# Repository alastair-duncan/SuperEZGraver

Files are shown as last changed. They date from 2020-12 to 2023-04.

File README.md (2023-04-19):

# SuperEZGraver

This is the Super EZ Graver project documentation. If any of the documentation doesn't make sense or links are broken etc please let me know and I'll do my best to fix it.

## Background

I started engraving early in 2019 after coming across some engraving videos by [Shaun Hughes](https://www.youtube.com/c/express375/videos) on YouTube. I started off with some push engraving while I ordered up the parts for Shaun's "Home made hand engraving machine". I built one of these and proceeded to hack my way through some brass and copper practice plates and I also enjoy making jewellery with enamel. I have now aquired a microscope which has had a marked effect on my engraving, previously I used an optivisor with an added loupe but it is not adequate for my old eyes.

Shaun had the idea of a solenoid powered engraving system over 2 years ago and posted a video on [YouTube](https://www.youtube.com/watch?v=2177lFeMcNw) and one of the engraving forums. He wasn't the first to come up with the idea, as far as I can find out that was [Steve Lindsay back in 1979](https://www.handengravetools.com/air-engraver-evolution.htm). So its nothing new although the availability of cheap electronic components and the advent of 3d printing has enabled me to put these together to make the Super EZ Graver. He also has tinkered with a Rolson engraver uses an AC driven laminated solenoid and power is regulated using a fan speed controller [YouTube](https://youtu.be//Ke8bDoJ-2io). Jerry Moralles uses a similar tool to engrave coins very effectively: [YouTube](https://www.youtube.com/channel/UC4XOksM98SMPymVrHOIaOxg). He also has made some additions that allow for the mounting of small abrasive stones to mechanise sanding and finishing very effectively.

Prior to this the McShirley power mallet utilises very similar technology by using a solenoid with presets for power and speed and a number of potentiometers which are used for fine control, you can view their 1975 [patent here](https://patentimages.storage.googleapis.com/81/7c/a0/0b0333b2f1563e/US3921044.pdf). There is also a video showing the [McShirley Power Mallet in action](https://www.youtube.com/watch?v=bn_Ea9L7uJU)

The Super EZ Graver that I have built is based around a XRN-13/30TLS solenoid. This is a small tubular solenoid that is 13mm in diameter and 30mm long. It will not plow its way through all materials put before it. You may find that for your purpose it does not pack the punch that you want but it suits me. I've had to adapt my engraving so that it is a bit more refined, which I think is an improvement for me, I no longer bury the tool and break tips. There may be a solenoid out there that will give all of the power and finess that everyone needs in a small package but I doubt it, I suspect that more than one toolpiece will be required and hopefully I'll add more designs and information to this project when it becomes available.

The controller and power source can handle much more powerful solenoids but I've only tried out a couple, I've made a [list of the ones I've tried](docs/solenoids.md) and added some comments. If you've tried others let me know and I'll add them to the list.

There are now 2 versions of the controler that I've built. The original based on the Ardiono Uno and the newer version based on the Pi Pico. The Pi Pico does not require a separate PWM "speed" controller for regulation of the power sent to the solenoid.

[Ardiono Uno controller](Arduino.md)

[Pico controller](Pico.md)

# Handpiece

I've created two 3d modelled handpieces in the open source 3d modelling application [Blender](https://www.blender.org/). 

there are now mk2 and mk3 versions 

### Mk2 Handpiece

The [blender source files](docs/design/XRN13-30TLS/mk2/blender) are available to download as well as the [stl](docs/design/XRN13-30TLS/mk2/blender/stl). There is a YouTube video on how to [setup the handpiece](https://www.youtube.com/watch?v=aNY35ATTJbg) and also the [Mk2](https://youtu.be/sa4kAdcZSkc) version which has a brass sleve insert. This was first produced using petg but it may be better to use a more heat conductive material such as [ice9](https://tcpoly.com/shop/) for better heat dissapation. I've not tried this yet.

[Anarasha](https://www.youtube.com/channel/UCKSbczGXmN4zeG3NeuPGLAg) had a problem with the blender version of the 3D model as the blender model has tolerances built in to it which causes problems with his slicer(I think). He has kindly produced a [fusion360](docs/design/XRN13-30TLS/fusion360) model of the handpiece which has the [stl](docs/design/XRN13-30TLS/fusion360/stl) and STEP files if this suits you better.

There are also some variations contributed by [ps-bond](https://github.com/ps-bond) one of these will allow the use if the solenoid without removing the screw boss.

### Mk3 Handpiece

This handpiece has the addition of a mount for a 25mm fan and is experimental. It suits my hand size and is comfortable. There are no threads on this handle, it does require some 2.5mm machine screws and nuts and a threaded insert in the handle for a stroke length adjuster. STL can be found [here](docs/design/XRN13-30TLS/mk3/stl). There is a video of the handpiece available [here](https://youtu.be/Q9xFH1qhLhE). The handpiece works without the fan but if you want some additional cooling when pushing the Super EZ Graver hard then the fan really helps. Something like [this](https://www.google.com/search?q=micro+fan+25mm+12v+dc) I've used a 12v dc version but there are other voltages available.

### Mk1 Handpiece
The first handpiece that I made was fabricated from brass and delrin. A YouTube video is available for the [handpiece](https://www.youtube.com/watch?v=D4yPBS8mucQ) along with a video on the handpiece [design refinement](https://www.youtube.com/watch?v=ALAtECnq1Rg)

# Gravers et al

[Carbide rods - UK](http://intertool.co.uk.websitebuilder.prositehosting.co.uk/carbide-rod)

[Carbide rods - US](https://centennialcarbide.com/products-page/carbide-rod-blanks/)

[3/32" HSS graver blanks - UK](https://www.ebay.co.uk/itm/360515374956) or [Gloster Tooling Supplies](https://www.glostertooling.co.uk/)

[Carbalt gravers](https://www.airgraver.com/graver-blanks.htm)

[Graver sharpening templates](http://airgraver.com/sharpening.html)

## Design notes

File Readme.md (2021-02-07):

The original design by Alastair Duncan was absolutely amazing. 
However, upon printing it on my rather well tweaked printer, some of the parts were way too loose.
I thought I couldn't be the only one who had such issues, so I recreated the entire model in Fusion 360 for easy editing, scaled so all the parts fit when I printed them and decided to upload both my Fusion 360 and STEP file here so others could make easy changes without Blender as well. 

I also uploaded my versions of the STL files. 

The functionality hasn't been changed at all, just the tolerance of the threads.

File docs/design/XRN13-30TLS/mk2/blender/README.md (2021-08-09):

Remember to watch the [construction video](https://youtu.be/sa4kAdcZSkc)
This design requires 9/32" brass tubing (K&S has a suitable wall thickness) & a soldered brass peg

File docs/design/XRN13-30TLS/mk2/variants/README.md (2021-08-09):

handpiece_6.5mm_v2_1.stl - this is a variant on the V2 handpiece that does not require a brass tube fitted.
Barrel of the handpiece has been extended 4mm to accomodate the threaded section of the solenoid (so it is no longer essential to cut off the threaded section); internal space has been expanded slightly to allow for easier insertion.

Protruding length of the piston should be reduced to a minimum of 3.2mm - this will allow for 2.5mm extension of the collet.

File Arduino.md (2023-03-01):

# Arduino Uno Controller

## Parts list.

Some of the links are to google searches, this is because actual products will become unavailable at some point so a list of products that you can select from is probably better.

[Arduino Uno](https://store.arduino.cc/arduino-uno-rev3), this is a link to the official Uno page. You can get unofficial versions much cheaper. Other Arduinos can be used but this is a cost effective board which can be run off the same 12VDC power supply so makes it very convenient. [Ebay arduinos](https://www.google.com/search?q=arduino+uno+ebay&oq=Arduino+uno+ebay)

[Mosfet](https://www.google.com/search?q=15A+400W+DC+5V-36V+Mosfet) Link to google search for appropriate mosfet. This is used by the Arduino to send a pulse of electricity to the solenoid.

[PWM power controller](https://www.google.com/search?q=DC+6-60V+12V+24V+36V+48V+30A+PWM+DC+Motor+Speed+Controller+(PWM)) Link to google search for appropriate PWM opwer controller. This is used to control how much power is sent via the mosfet to the solenoid.

[Power Supply](https://www.google.com/search?q=DC+12V+5A+to+50A+Amp+110V+220V+Power+Supply+12V+-+AC+110+-+220) Link to google search for appropriate 12VDC power supply. The XRN-13/30TL solenoid draws a maximum of 23SuperEZGraverw which is around 1.8 amps so a 5amp power supply will be ample.

[Foot pedal - potentiometer](https://www.google.com/search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) Link to google search for potentiometer foot pedal. I use this for control of the PWM power controler. It is not absulutly necessary as you can use the potentiometer that comes with the PWM  controller. It does add some flexibility to allow alteration of how much power is transmmitted while engraving. If you want to use one of these you will need to remove the potentiometer on the speed controller and wire the foot pedal in. I removed the extra stuff in the pedal and wired straight to the potentiometer in the pedal. There is a you tube video of the [insides of the pedal](https://www.youtube.com/watch?v=_dJo02ZIpgE)

[Foot pedal - hall effect](https://www.google.com/search?q=Electric+Scooter+Foot+Throttle+Speed+Pedal+Accelerator+Bike+Golf+Cart+Go+Kart) Link to google search for hall effect foot pedal. I use this foot pedal for controling the frequency of the pulses that are sent to the solenoid. You could use a further potentiometer foot pedal for frequency control. The Arduino code will require appropriate parameter changes to use the potentiometer foot pedal.

[Solenoid](https://www.google.com/search?q=XRN-13%2F30TL+12vdc) Link to google search for XRN-13/30TL 12vdc solenoid. This is the tubular solenoid that I've used to power the  fabricated and 3d printed handpieces

 (I did cut off the screw thread and the piston needs to be cut down. I also removed the label from the solenoid so that it's not so tight in the handpiece. Once you have cut off the screw thread from the solenoid and cleaned it up with a file this can be installed into the handpiece. Screw in the inner sleeve add the spring and the piston. Press the piston in so that it's hard up against the solenoid body, then offer up the QC toolholder. You should be able to take a measurement for how far it is protruding from the handpiece. The measurement needs to be for the part which can move inside the handpiece. Subtract 3mm from that measurement and that is how much you should remove from the end of the piston. What you are aiming for is, when the piston is fully depressed the QC toolholder protrudes no more than 3mm from the flat area of the handpiece. Taking off less is better than taking off too much; you can always cut off a bit more but it's much harder to add material back. 2.5mm protruding is probably optimal with the piston fully depressed.)

[Cable connectors](https://www.google.com/search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) Link to google search for cable connectors. For connection of the arduino to the other components.

### Other parts

[Cable](https://www.google.com/search?q=Speaker+Cable+2+x+1.5+mm) Link to google search for speaker cable. I've used a cheap speaker cable which seems to work fine.

[Heat shrink tubing](https://www.google.com/search?q=heat+shrink+tubing) Link to google search for heat shrink tubing. If you are soldering cables together the assortment packs are useful for insulation once they are soldered.

You will also require a box to put everything in. I use a clear plastic storage box.

## Arduino code

The code for the arduino can be found in the [src](src) directory of this github project.

[Arduino programming setup guide](https://www.arduino.cc/en/Guide/ArduinoUno) Link to the  guide for setting up the programming environment for the Arduino.

[Arduino setup YouTube](https://www.youtube.com/watch?v=ELUF8m24sZo) Link to the video guide for setting up the programming environment for the Arduino.

## Wiring diagram

[Mosfet and Arduino background](https://bildr.org/2012/03/rfp30n06le-arduino/) This is the background to mosfets for power control using the arduino. I've used a mosfet module that has the mosfet, diode and resister in a package so its much easier to connect the components up.

#### One foot pedal
Wiring Diagram
#### Two foot pedals, one hall effect, one m-audio
Wiring Diagram
#### Two foot pedals, both m-audio note the addition of a jumper between D7 and ground
Wiring Diagram

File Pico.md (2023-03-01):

# Raspbery Pi Pico controller

## Parts list.

Some of the links are to google searches, this is because actual products will become unavailable at some point so a list of products that you can select from is probably better.

[Pi Pico](https://www.google.com/search?q=raspberry+pi+pico&oq=raspbery+pi+pico), this is a link to a google search. 

[Mosfet](https://www.google.com/search?q=15A+400W+DC+5V-36V+Mosfet) Link to google search for appropriate mosfet. This is used by the Pico to send a pulse of electricity to the solenoid.

[Power Supply](https://www.google.com/search?q=DC+12V+5A+to+50A+Amp+110V+220V+Power+Supply+12V+-+AC+110+-+220) Link to google search for appropriate 12VDC power supply. The XRN-13/30TL solenoid draws a maximum of 23w which is around 1.8 amps so a 5amp power supply will be ample.

[Foot pedal - potentiometer](https://www.google.com/search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) Link to google search for potentiometer foot pedal. I use this for control of the PWM power controler. I use 2 of these one for power and one for rpm. These can be replaced by potentiometers I've not tested this on the Pi controller. It does take a little while to get used to 2 pedals but I wouldn't be withoput them now that I've got used to them. If I can get used to them anyone can ;-) I removed the extra stuff in the pedal and wired straight to the potentiometer in the pedal. There is a you tube video of the [insides of the pedal](https://www.youtube.com/watch?v=_dJo02ZIpgE)

[Solenoid](https://www.google.com/search?q=XRN-13%2F30TL+12vdc) Link to google search for XRN-13/30TL 12vdc solenoid. This is the tubular solenoid that I've used to power the  fabricated and 3d printed handpieces

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

[oled display](https://www.google.com/search?q=oled+display) Link to google search for OLED display. To show the power and rpm. I found this useful for debug but its not essential and I don't use it when engraving. I don't know if the code will throw up problems if the OLED is not present, I've not tried it. If you don't want the OLED you may have to remove the code that drives it. 

[Cable connectors](https://www.google.com/search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) Link to google search for cable connectors. For connection of the arduino to the other components.

### Other parts

[Cable](https://www.google.com/search?q=Speaker+Cable+2+x+1.5+mm) Link to google search for speaker cable. I've used a cheap speaker cable which seems to work fine.

[Heat shrink tubing](https://www.google.com/search?q=heat+shrink+tubing) Link to google search for heat shrink tubing. If you are soldering cables together the assortment packs are useful for insulation once they are soldered.

You will also require a box to put everything in. I use a clear plastic storage box.

Cable connectors, I don't know what connectors are best, I've tried some audio connectors but wasn't happy with them if you have some insight into what would be suitable let me know and I'll give them a try.

## pico micropython code

The code for the pico can be found in the [src](src) directory of this github project.

[Pico programming setup guide](https://projects.raspberrypi.org/en/projects/getting-started-with-the-pico) Link to the  guide for setting up the programming environment for the pico.

There are lots of video guides for setting up the pico environment use google ;-)

## Wiring diagram

#### Two foot pedals, both m-audio
Wiring Diagram

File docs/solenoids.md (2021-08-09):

XRN-13/30TLS Small light general purpose tubular solenoid 12vdc and 2Vdc versions are available 21W good for smaller fine engraving 50/100gms force. There does not seem to be any difference to me in power between the 12Vdc and 24Vdc models. I've pushed 24Vdc throuch the 12Vdc model and this increases the power a lot but at the expence of more heat - too much, I managed to melt one of the 3d printed handles :-)
(Note that in the current design this needs the threaded section of the solenoid sawn off & the piston shortening)

JF-0530B used by [Thinh Tran](https://www.youtube.com/channel/UCPPznlrRBxmUakzwW97TLtA) I've got one of these but have not tried it yet)t it is an open frame solenoid and comes in 12Vdc and 24Vdc versions with a rating of 5N force so should pack a stronger punch but would require a further design for the handpiece.

JF-Z05 I think this is the big solenoid that has been used by [BZ Urison](https://www.youtube.com/channel/UCu4CvU6LO0kVl6MlCuTM63g) but I'm not certain. Its a 45N 12Vdc and 24Vdc open frame solenoid and he has removed the frame and is around 25mm in diameter and around 50mm in length so is big but has more power than anyone should need. One of the problems I have with the spec on this one is that reported power consumption is not consistent 400mA but on the solenoid image it states 2A that's a big difference. The problem with more power is that tips are more likely to break. The specs vary so much you don't know what to believe!

XRN-19/42TL I have a couple of these and hooked them up without a handpiece but although they are much bigger they do not produce any more force than the XRN-13/30TLS which I'm surprised at. There are 12Vdc and 24Vdc versions

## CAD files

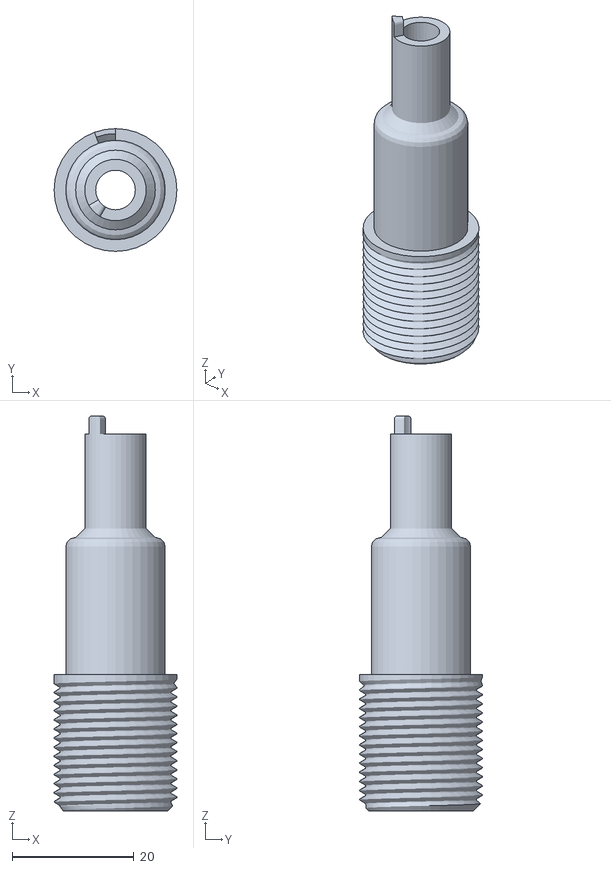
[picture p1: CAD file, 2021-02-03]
docs/design/XRN13-30TLS/mk2/blender/stl/MainBody.stl
20.2 x 20.2 x 65.0

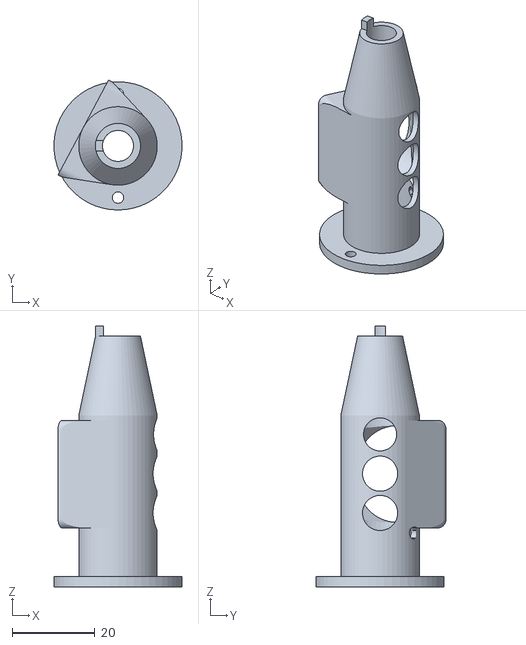
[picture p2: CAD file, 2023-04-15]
docs/design/XRN13-30TLS/mk3/stl/MainBarrelShort.stl
30.9 x 31.4 x 63.1

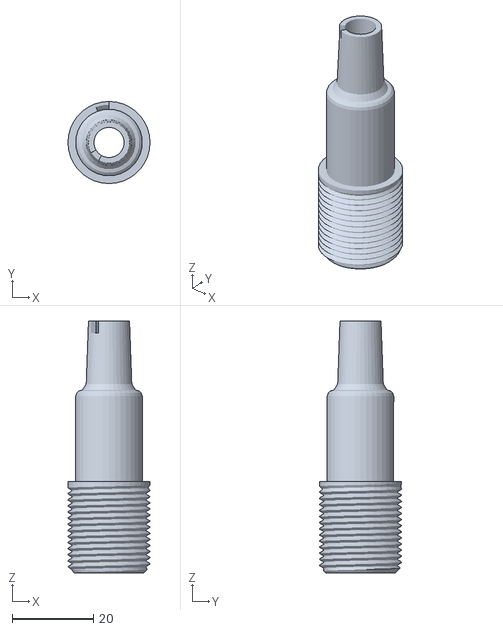
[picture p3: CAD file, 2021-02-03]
docs/design/XRN13-30TLS/mk2/blender/stl/MainBodyMk2.stl
20.2 x 20.2 x 62.0

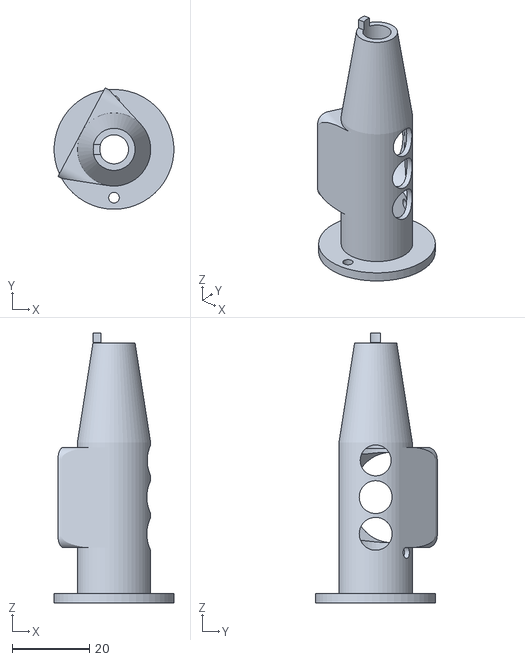
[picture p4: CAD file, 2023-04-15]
docs/design/XRN13-30TLS/mk3/stl/MainBarrelLong.stl
30.9 x 31.4 x 69.9

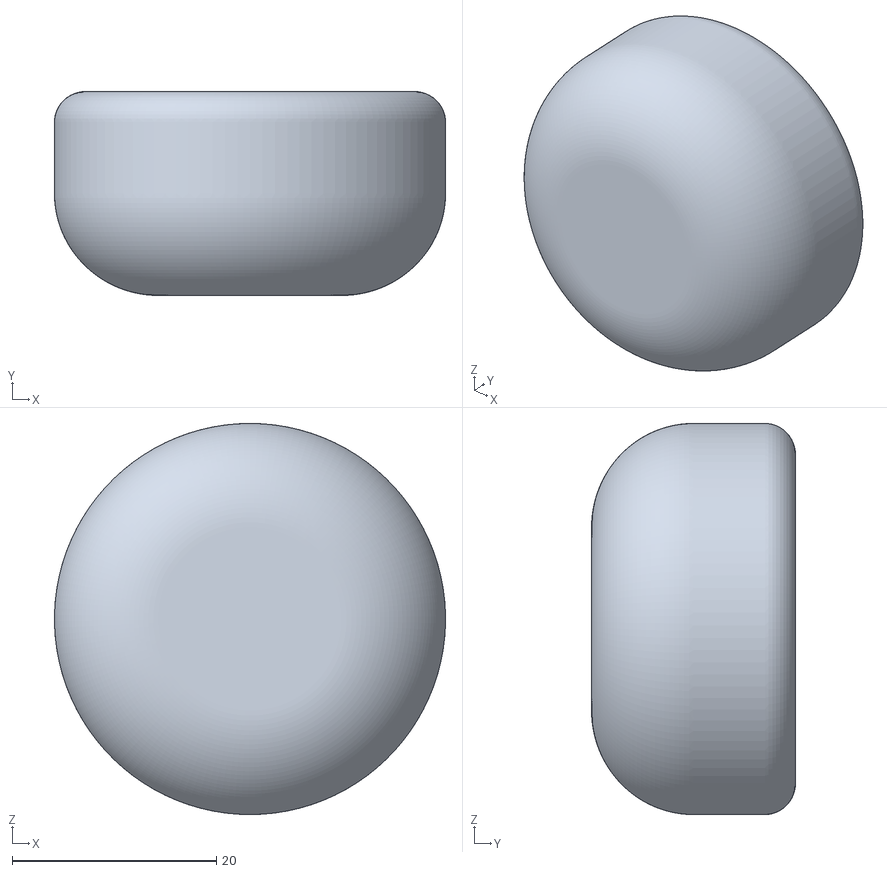
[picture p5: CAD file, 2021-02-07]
docs/design/XRN13-30TLS/mk2/fusion360/stl/Handle.stl
38.3 x 20.0 x 38.4

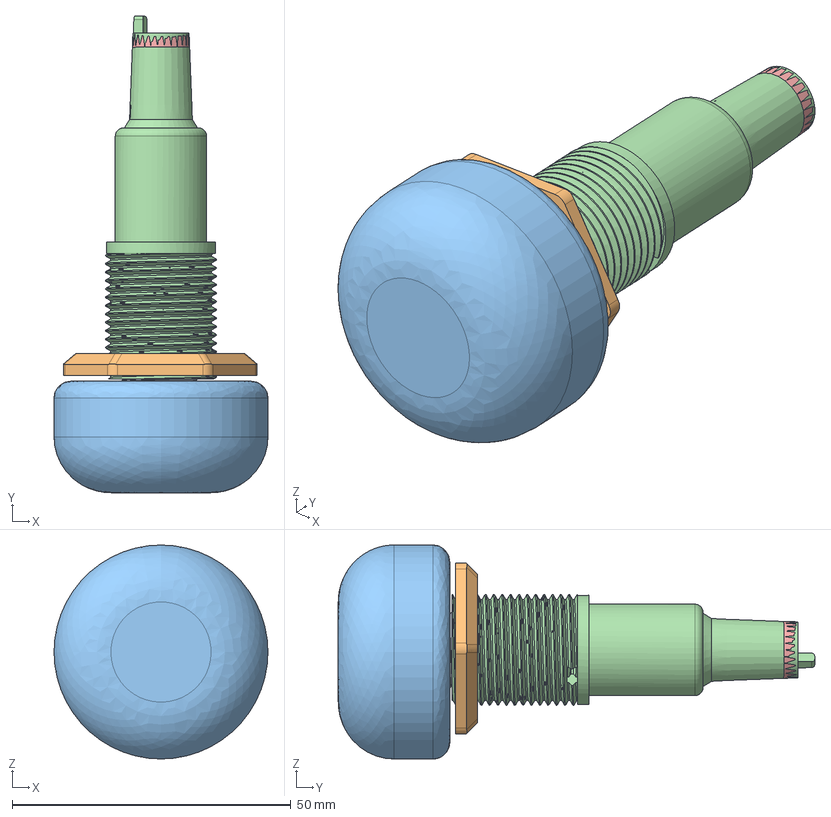
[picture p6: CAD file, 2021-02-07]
docs/design/XRN13-30TLS/mk2/fusion360/SuperEZGraverV21.step
38.4 x 85.4 x 38.4 mm

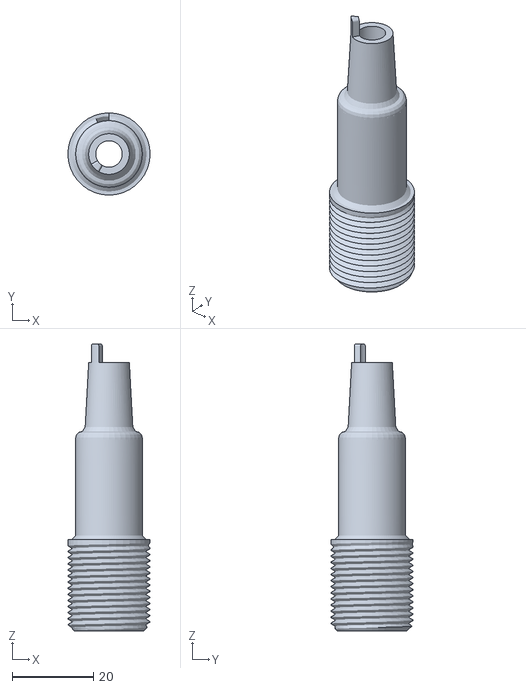
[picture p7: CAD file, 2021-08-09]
docs/design/XRN13-30TLS/mk2/variants/handpiece_6.5mm_v2_1.stl
20.2 x 20.2 x 70.5

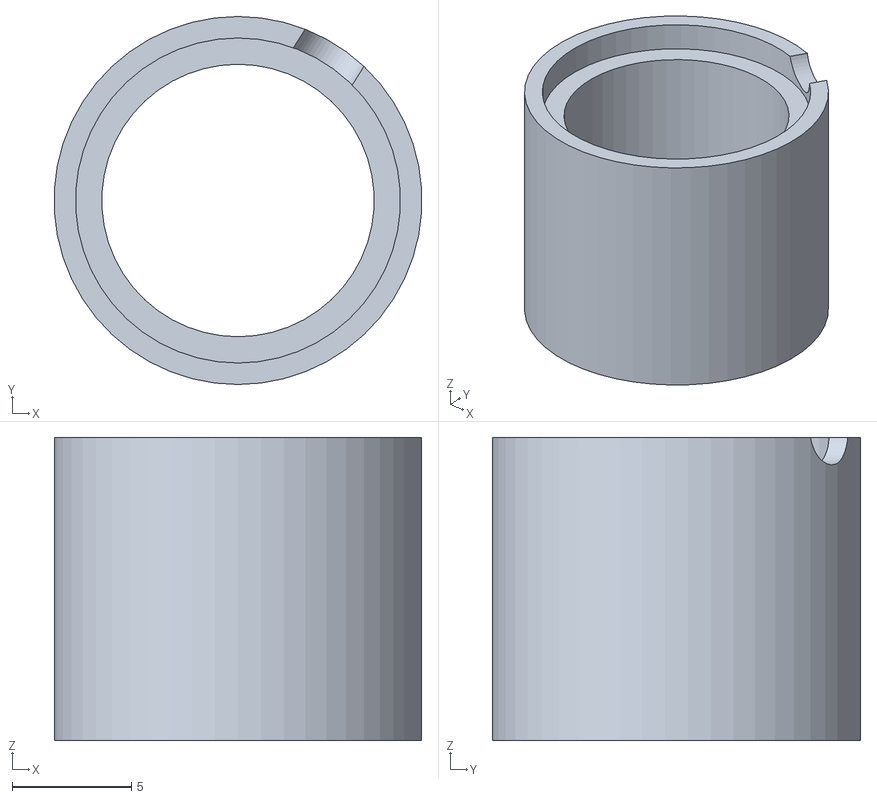
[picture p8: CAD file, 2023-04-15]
docs/design/XRN13-30TLS/mk3/stl/InnerSleve.stl
15.4 x 15.4 x 12.7

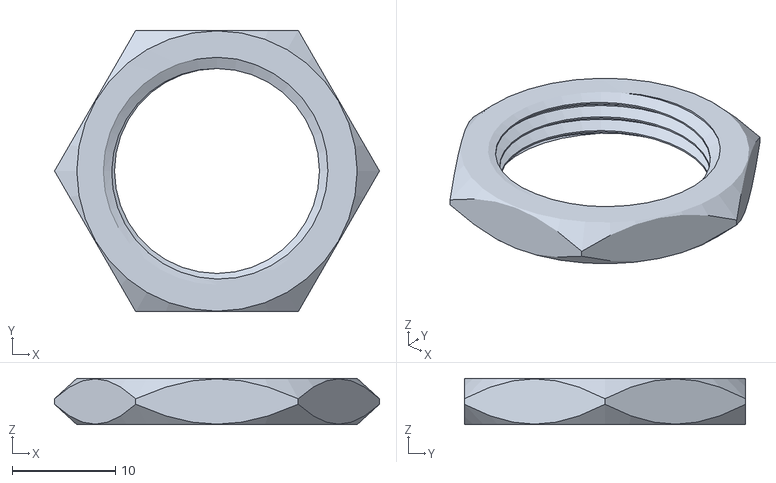
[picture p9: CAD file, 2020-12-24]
docs/design/XRN13-30TLS/mk2/blender/stl/Locknut.stl
31.5 x 27.3 x 4.50

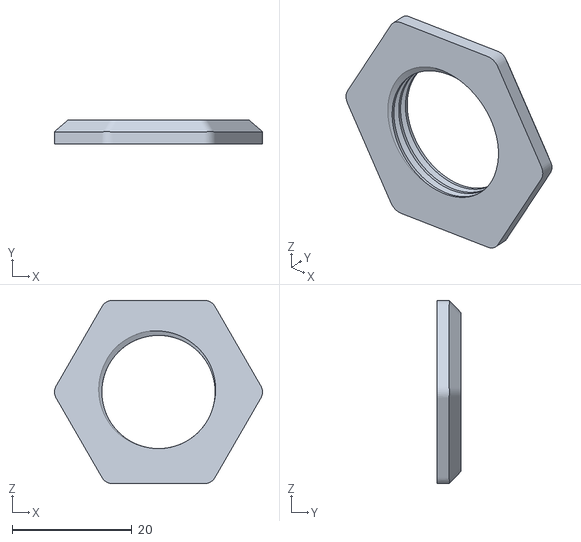
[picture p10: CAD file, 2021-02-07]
docs/design/XRN13-30TLS/mk2/fusion360/stl/Locknut.stl
34.7 x 4.00 x 30.6

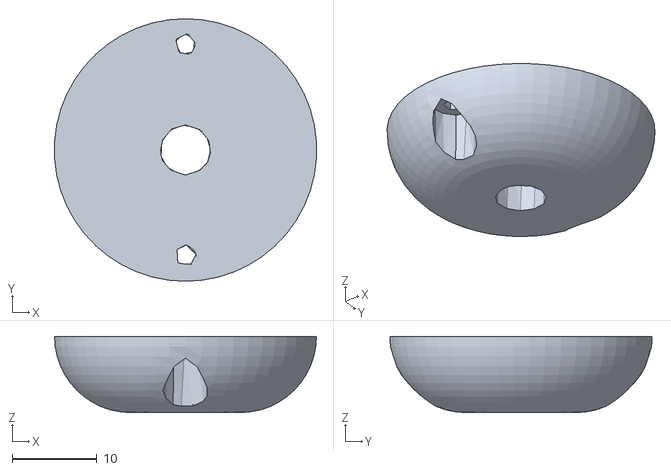
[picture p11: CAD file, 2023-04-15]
docs/design/XRN13-30TLS/mk3/stl/Handle.stl
30.9 x 31.0 x 9.00

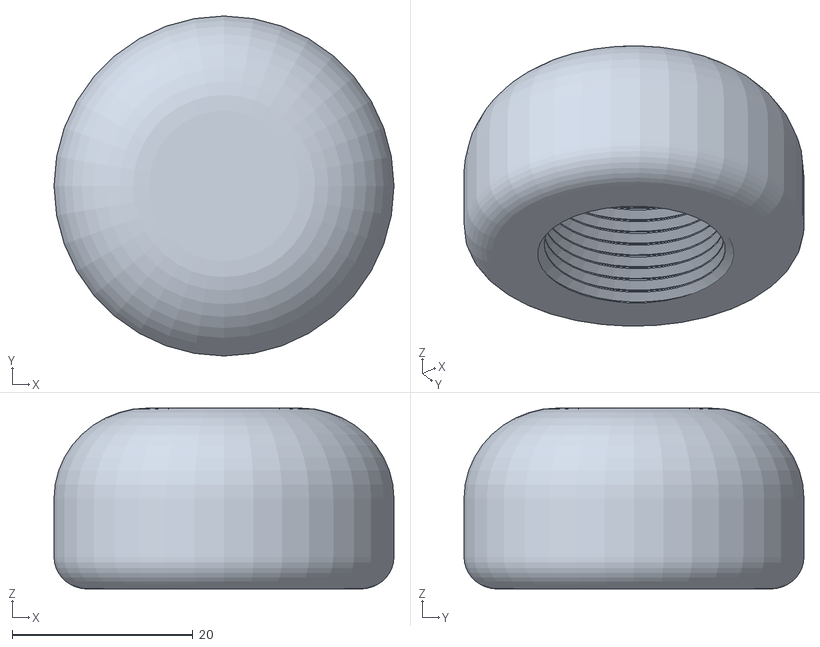
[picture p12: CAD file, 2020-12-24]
docs/design/XRN13-30TLS/mk2/blender/stl/Handle.stl
37.6 x 37.6 x 20.0

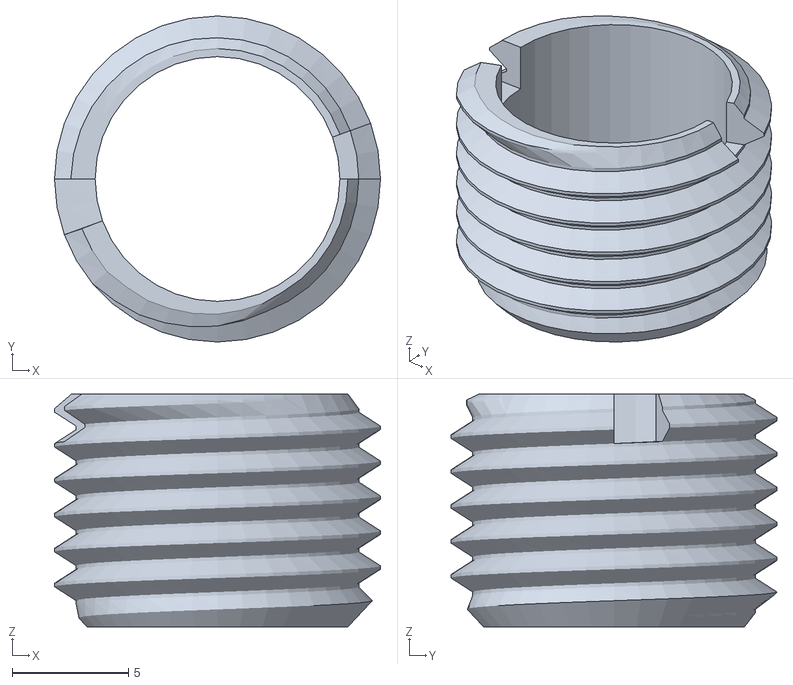
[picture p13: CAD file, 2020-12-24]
docs/design/XRN13-30TLS/mk2/blender/stl/InnerSleeve.stl
14.0 x 14.0 x 10.0

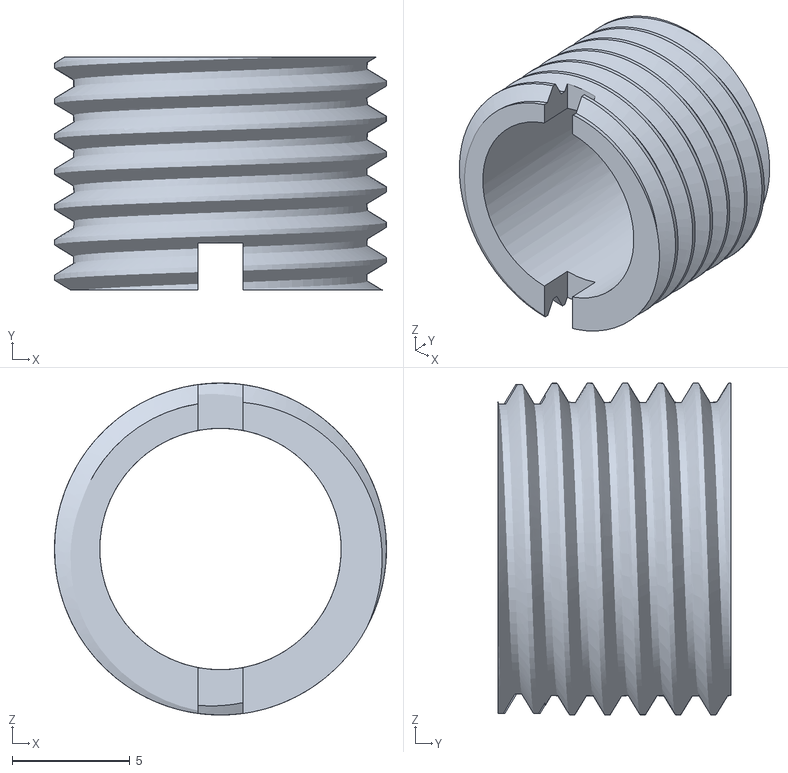
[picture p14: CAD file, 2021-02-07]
docs/design/XRN13-30TLS/mk2/fusion360/stl/InnerSleeve.stl
14.1 x 9.90 x 14.1

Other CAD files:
docs/design/XRN13-30TLS/mk2/fusion360/stl/Handpiece.stl
docs/design/XRN13-30TLS/mk2/fusion360/stl/HandpieceMK2.stl
docs/design/XRN13-30TLS/mk2/blender/Handle.blend
docs/design/XRN13-30TLS/mk2/blender/InnerSleeve.blend
docs/design/XRN13-30TLS/mk2/blender/Locknut.blend
docs/design/XRN13-30TLS/mk2/blender/MainBody.blend
docs/design/XRN13-30TLS/mk2/blender/MainBodyMk2.blend
docs/design/XRN13-30TLS/mk2/fusion360/SuperEZGraverV21.f3d

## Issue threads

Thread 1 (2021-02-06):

Not an issue, but a question about the files

Anarasha, 2021-02-06:
Hello.
So, I got suggested this project by someone I'm talking to, and I am a huge fan of all the work you put in.
However, I had some issues with some of the parts being way too large and loose when printed on my printer(maybe the printer you used to print yours was less dimensionally accurate, I don't know, it doesn't matter).
So I took your original model and re-created it in Fusion 360 and adjusted it until all the parts fit together well when I printed it.

Are you okay with me uploading the Fusion 360 and the STEP files as well as my versions of the STLs? I would upload them as pull requests here on Github, but I wanted to ask you first :-)

alastair-duncan, 2021-02-06:
Hi Anarsha,

I'd be happy to have the additions, a pull request is fine, if you could add a readme to describe what and why so that others may benefit that would be great.

Thank you

Closed 2021-02-08.

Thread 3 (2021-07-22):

Separate PWM needed?

ps-bond, 2021-07-22:
Given the Arduino can directly output PWM to the MOSFET, can I ask what the design decison is to use an external PWM from the MOSFET?  I may have missed something., of course.
(And is there really no option to set this as a low prio issue???)

alastair-duncan, 2021-07-22:
The PWM output from the arduino is 5v and the max current is limited to what the board can handle(50mA if I remember correctly) The PWM output from the external PWM is 6-60v and the max current is 30A - limited by the power supply that is connected.

I'm not an electronics engineer so there may be a way to do this with the arduino controlling the pwm. I wanted to be able to put together a system from off the shelf components that kept the complexity of the electronics and code to a minimum.

ps-bond, 2021-07-22:
I'll sit down and scribble some calculations - the code shouldn't get much more complex, just need to watch out for duty cycle on the solenoid to stop it overheating.  If I'm right, it'll knock the cost down some more.  Will feed back to you.

Embedded software engineer & jeweller, depending on day of the week :)

ps-bond, 2021-08-08:
Now tested (using an ESP8266 and microPython - not critical, it can be tweaked to other boards) and yes, PWM does work as might be expected.  In addition to the solenoid, I've got a FET module, a diode and the microcontroller (and an inexpensive 12V PSU).  Only a command line test program at the moment, but it allows me to play with settings easily.

alastair-duncan, 2021-08-08:
Thanks, I'll take a look at what you have done, get some bits and have a play myself. I've not come across the ESP8266 board but it looks very interesting and the use of python is nice.

ps-bond, 2021-08-08:
The ESP8266 is overkill (Wifi enabled gravers?) but it was the first board I grabbed - it'll also run on a number of other boards (including the Pi Pico, for example - £3.60).  MicroPython allows for a quick & easy approach on tweaking development, but it does have some downsides (it runs out of memory quickly because it's doing so much more than a simple compiled program).

I have an idea or two on touchscreen UIs; undecided if I'll switch to C++ for that.  Or C, doesn't really matter which :)

Not done yet...  Oh, and I've been tweaking readmes a little as well.  And my handpiece - based on yours - doesn't need the brass insert.

alastair-duncan, 2021-08-09:
There is a module that will do all of the signal generation  and controlling of the duty cycle but the interface to it is really poor.

https://www.ebay.co.uk/itm/192338137447

It has a serial interface but this is really flaky you can poke it once( I used the Arduino to do this) and change the settings but it requires a hard set to be able to do it again. Its a shame because it has a display and apart from a poor interface it works really well.

ps-bond, 2021-08-09:
Aside from the peak frequency, I'm not sure that gives much more than the uC PWM output offers (and it's much easier to fettle the output behaviour).

If it's a display you want - http://www.lilygo.cn/prod_view.aspx?TypeId=50044&Id=1126&FId=t3:50044:3
(Still an overkill microcontroller!)

alastair-duncan, 2021-08-09:
I like being able to see the power output at a glance. It's not going to be
a complete view of power as the stroke length also has an impact on the
power of the strike. Is it really important? Probably not as I do some test
cuts to see how it feels before doing any cuts that count.

I looked at the signal generator a while ago to see if there were better
solutions to what I had.

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

ps-bond, 2021-08-10:
Next version I'll incorporate a simple display - I might have to rethink my threading approach as it's not fully supported on microPython.  If it does what I want, fine; if not, I'll fall back to a simpler approach.

Closed 2021-08-08.

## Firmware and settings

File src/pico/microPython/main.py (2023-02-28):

from machine import Pin, PWM, ADC, I2C
import utime, math, _thread
from ssd1306 import SSD1306_I2C
from oled import Write, GFX, SSD1306_I2C
from oled.fonts import ubuntu_mono_15

# setup the oled display
WIDTH =128
HEIGHT= 32
i2c=I2C(0,scl=Pin(17),sda=Pin(16),freq=400000)
oled = SSD1306_I2C(WIDTH,HEIGHT,i2c)
write15 = Write(oled, ubuntu_mono_15)


#output pin for PWM values this is connected to the mosfet
pwm13 = PWM(Pin(13))
#assign the pin to read the power values from
pot_pwm = ADC(28)
#assign the pin to read the frequency values from
pot_freq = ADC(27)
#set the frequency of the pwm output
pwm13.freq(400)
#setup some variables to be used in the while loop
duty_cycle_val = 0
pot_freq_val = 0
#the frequency value is in the range of 0 to 65536 which will be divided by the quantisation_factor which gives 65536//quantisation_factor different speed values
#this seems to work ok. If a finer granularity is required then change the quantisation_factor
quantisation_factor = 655
#using 100 here unsigned int16 max
max_freq_sleep = 65536//quantisation_factor
# adjust this value if a faster frequency is required, lower values = more rpms - remember that lower values will produce more heat
default_sleep_freq = 25
# this value determins how long the power is applied to the solenoid. 15ms seems to be the lowest for the 13/30 for a full length stroke
# this may need altering for different solenoids - higher values will produce more heat.
default_sleep_duty = 15
#values from 1 to slow_speed_value will be slowed right down 
slow_speed_value = 30
duty_percent = 0
freq_rpm = 0

sLock = _thread.allocate_lock()

def updateDisplay():
    
    while True:
        #percentage calc for the display
        duty_percent =  math.ceil((duty_cycle_val / 65536) * 100)
        write15.text("freq:           ", 0, 0)
        write15.text("duty:           ", 0, 15)
        write15.text("freq: " + str(freq_rpm), 0, 0)
        write15.text("duty: " + str(duty_percent), 0, 15)
        oled.show()

# map function taken directly from arduino codebase
def map(value_to_map, fromLow, fromHigh, toLow, toHigh):
    """
        Re-maps a number from one range to another. That is, a value of fromLow would get mapped to toLow, a value of fromHigh to toHigh, values in-between to values in-between, etc.

        Parameters
        ----------unsigned int16
        value_to_map : value read from the pin
        ----------unsigned int16 max
        fromLow: the lower bound of the value’s current range.
        ----------unsigned int16 
        fromHigh: the upper bound of the value’s current range.
        ----------unsigned int16 
        toLow: the lower bound of the value’s target range.
        ----------unsigned int16 
        toHigh: the upper bound of the value’s target range.
    """
    return int((value_to_map - fromLow) * (toHigh - toLow) / (fromHigh - fromLow) + toLow)
        
# as the pi pico has 2 cores run the oled update in a thread as it will affect the timing otherwise
# oled device is pretty slow and will block execution and hence slow down the system
# no need for synchronisationas its a read operation from a shared global variable
#synchronisation affects the timing of the system, slows everything down.
_thread.start_new_thread(updateDisplay,())

print(" **************************************************************** ")
print(" Super EZ Graver pi pico software ")
print(" **************************************************************** ")
while True:
    
    #freq_rpm = 0
    pot_freq_val = pot_freq.read_u16()//quantisation_factor
    
    if (pot_freq_val > 1 ):
        #read the value from the foot pedal potentiometer range of 0-65536
        duty_cycle_val = pot_pwm.read_u16()
        #print("duty " + str(duty_cycle_val))
        #remap the value to one that is meaningful, anything under 30000 will not power the solenoid
        duty_cycle_val = map(duty_cycle_val, 150, 65536, 20000, 65536)
        # the duty cycle value has been remapped from 30000 to 65536 but the least value should be 0 otherwise
        # there will still be power being transmitted to the solenoid at the lowest value even if there is
        # not enough power to move the piston so anything under the minimum swithc it off
        if (duty_cycle_val < 30000):
            duty_cycle_val = 0
        
        #print("duty " + str(int((duty_cycle_val / 65536) * 100)))
        pwm13.duty_u16(duty_cycle_val)
        # the value of 15ms or above alows for the full travel of the XRN13/30 solenoid a different solenoid may require adjustment of this value 
        #print("duty_ns " + str(pwm13.duty_ns()))
        utime.sleep_ms(default_sleep_duty)
        #make sure there's no power
        pwm13.duty_u16(0)
        # a linear ramp up of speed is not necessarily required so manipulate is slightly
        #so that when its slow its really slow
        #if its a slow speed value slow it right down
        if(pot_freq_val < slow_speed_value):
            # delay before next hit, ramp up the speed slowly so that its a smooth transition
            # this is in addition to the rpm sleep but only added for lower rpms
            rpm_sleep_time = ((slow_speed_value  - pot_freq_val) * 10)
            #print("rpm_sleep_time = " + str(rpm_sleep_time))
            utime.sleep_ms(rpm_sleep_time)
        else:
            #needs to be reset if its done here the display behaves itself better
            freq_rpm = 0
        freq_rpm = 65536 // (freq_rpm + (default_sleep_freq + (max_freq_sleep - pot_freq_val)))
      
    else:
        freq_rpm = 0
    #switch off the power 
    pwm13.duty_u16(0)
    
    # this calculation smooths out ramp up, if the default_sleep_freq is used then its very top heavy, not much movement in the pedal before its at max rpm
    # this makes it much more usable - for me at least ;-)
    sleep_time = (default_sleep_freq + (max_freq_sleep - pot_freq_val))
    #print("sleep_time = " + str(sleep_time))
    #and go to sleep
    utime.sleep_ms(sleep_time)
     

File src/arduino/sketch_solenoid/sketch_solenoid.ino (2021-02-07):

/*
   Arduino Uno sketch to show how it can be used as a speed controller for
   driving a solenoid
*/


/*
    this is the pwm digital pin 2 in this example
*/
#define MOSFET_PIN 2

/*
 * This is the pin used to determin which type of pedal is connected
 * Not connected by default so assume its hall effect
 * if connected to ground then it will be detected as m-audio pedal
 */
#define JUMPER_PIN 7
/*
   sensor pin for the accellerator pedal
*/
#define ACCELERATOR_PEDAL  1

//default pedal type is hall effect
int pedal_type = 0;

#define QUANTIZATION_FACTOR 201
void setup() {
  // uncomment if you want to use the serial monitor on your computer
  Serial.begin(115200);
  // tell thje arduino that the mosfet pin is an output
  pinMode(MOSFET_PIN, OUTPUT);
  pinMode(JUMPER_PIN, INPUT_PULLUP);

  if (digitalRead(JUMPER_PIN) == LOW)
  {
    //jumper is inserted pedal type is m-audio
    pedal_type = 1;
    Serial.print("Pedal type is set for M-Audio ");
  }
  else{
    // default pedal type
    Serial.print("Pedal type is set for Hall effect pedal ");
  }
}

void loop() {
  /*
     grab the value from the sensor pin and map it to the quantization factor.
     In this example there will be 200 different speed values
     pot_value is the mapped potentiometer value
  */
  int pot_value;
  // hall effect footpedal values
  if(pedal_type == 0){
    pot_value = map(analogRead(ACCELERATOR_PEDAL), 180, 875, -2, QUANTIZATION_FACTOR);
    pot_value = QUANTIZATION_FACTOR - pot_value;
  } 
  else{
    // m-autio pedal
    pot_value = map(analogRead(ACCELERATOR_PEDAL),0,1023, 0, QUANTIZATION_FACTOR);
  }
  
  // uncomment if you want to see the values of the potentiometer in the serial monitor
  // Serial.print("acc ");
  // Serial.println( pot_value);

  //

  /*
     if the mapped potentiometer value is in the range
     0 to 199 then write to the mosfet pin
  */
  
  if (pot_value < 200) {
    //Serial.println( "About to write high");
    digitalWrite(MOSFET_PIN, HIGH);
    // this is to give the solenoid time to act, for different solenoids this may have to be larger!!
    delay(15);
    
    digitalWrite(MOSFET_PIN, LOW);
    //this is the speed control here. it also determins the duty cycle for the solenoid
    delay(pot_value + 25);
  } else
  {
    // if its out of the 0 - 199 range ensure that the mosfet is low
    digitalWrite(MOSFET_PIN, LOW);
    delay(pot_value+20);
  }

}

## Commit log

2020-12-24 initial design files ant arduino sketch
    [Handle.blend, Handle.stl, InnerSleeve.blend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]
2021-01-05 added wiring diagram
2021-01-19 removed 12v power as it screws things up
2021-02-03 mods to handpiece a mk2 handpiece
    [MainBody.blend, MainBody.stl, MainBodyMk2.blend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]
2021-02-07 merged pull request from Anarasha refactored
    [Handle.blend, Handle.stl, Handpiece.stl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]
2021-02-07 now checks pin 7 if connected it assumes the pedal in m-audio if not ists hall effect
2021-02-08 corrected wire colour for white
2021-08-06 Prep for new dev
    [handpieceV2_6mm_opening.stl]
2021-08-06 Added 6.5mm handpiece; fits holders from AliExpress
    [handpiece_6.5mm_opening.stl]
2021-08-06 Handpiece development
    [handpieceV2_6mm_opening.stl, handpiece_6.5mm_opening.stl, handpiece_6.5mm_v21.stl]
2021-08-06 More handpiece mods
    [handpiece_6.5mm_v21.stl, handpiece_6.5mm_v2_1.stl]
2021-08-07 Tweaks to readmes, initial design for threaded approach
2021-08-08 Constrain speed with 50% duty cycle on solenoid - experimental
2021-08-08 Added solenoid on time counter
2023-02-26 initial version of pico micropython works but needs tidying up
2023-03-01 Documentation for the Pi Pico, rearranged readme and split out arduino and pico readmes
2023-04-15 changed the design files to accomodate mk2
    [Handle.blend, Handle.stl, Handpiece.stl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]
2023-04-15 tidying up
    [Handle.stl, Handpiece.stl, HandpieceMK2.stl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]
2023-04-15 added stl directory to mk3 design
    [Handle.stl, InnerSleve.stl, MainBarrelLong.stl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]
2023-04-15 moved to stl directory
    [Handle.stl, InnerSleve.stl, MainBarrelLong.stl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]
